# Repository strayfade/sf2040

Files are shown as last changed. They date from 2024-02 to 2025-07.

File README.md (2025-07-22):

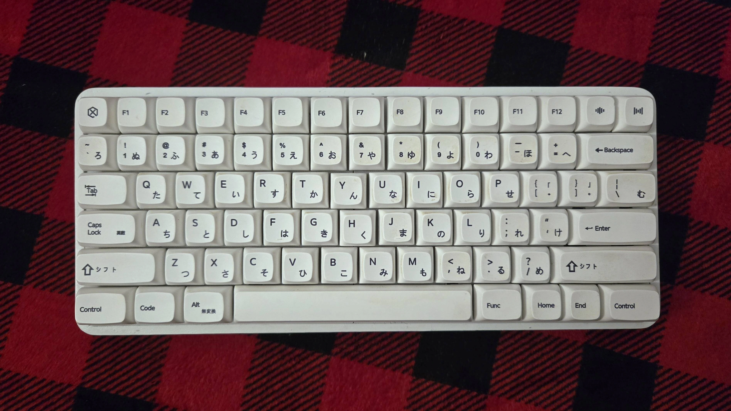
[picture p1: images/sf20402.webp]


<h1 align="center">sf2040</h1>

<p align="center">
    <a href="https://certification.oshwa.org/us002610.html">
        
    </a>
    <a href="https://qmk.fm/">
        
    </a>
</p>

### About

The sf2040 is a mechanical 76-key keyboard based on the [RP2040](https://datasheets.raspberrypi.com/rp2040/rp2040-datasheet.pdf) microcontroller from Raspberry Pi.

> This project has been certified by the OSHWA as open source hardware.
>
> ```html
> [OSHW] US002610 | Certified open source hardware | oshwa.org/cert
> ```

### Features

- USB Type-C Port
- Fully open-source/open-hardware design and firmware files
- **No LED backlight**
- **No Bluetooth/wireless connectivity**

### Assembly/Mechanical Information

**Required** parts:

- PCB ([Download Gerber](/pcb/Gerber/Gerber.zip))
- 3D-printed case ([Download .STEP](/case/Case.step))
- Keyswitch plate ([Download .STEP](/plate/Plate.step))
- _Your choice of 76 full-size MX-style keyswitches_
- MX-style Hot Swap Switch Mounts ([Amazon](https://www.amazon.com/gp/product/B0B4W9YMGM))
- Screw-in PCB Mount Stabilizers ([Amazon](https://www.amazon.com/gp/product/B0CN38CXQ3))

**Optional, but recommended** parts:

- 0.5mm Foam Switch Dampeners ([Amazon](https://www.amazon.com/gp/product/B0B942VCMV))
- Krytox 205 Grade 0 Lubricant
- Switch disassembly tools
- Case filler (I used polyester fiber)

### Firmware

This keyboard runs standard [QMK firmware](https://docs.qmk.fm/#/), configuration for which is included in this repository.

> The firmware can be downloaded pre-configured for this keyboard [here](/firmware/builds/sf2040.uf2).

The contents of the [firmware](/firmware) folder should be copied into QMK's working keyboard directory (usually `qmk_firmware/keyboards`) before building.

Build with support for VIA enabled:

```sh
qmk compile -kb sf2040 -km via
```

The RP2040's bootloader can be accessed by holding the **ESC** key while plugging in the keyboard. Then, simply drag-and-drop the output `.uf2` firmware into the bootloader folder.

This keyboard has been merged into the [QMK repository](https://github.com/qmk/qmk_firmware/tree/master/keyboards) and [VIA's keyboard repository](https://github.com/the-via/keyboards), meaning that it is fully compatible with the VIA online keyboard configuration software ([usevia.app](https://usevia.app))

> For more information about setting up and working with [QMK](https://docs.qmk.fm/#/) keyboard firmware, read the QMK documentation (https://docs.qmk.fm).

### License

The **sf2040** keyboard design and firmware is released under the **GPLv3** license. Contributions and pull requests to this repository are always welcome!

# Gallery

<div align="center">
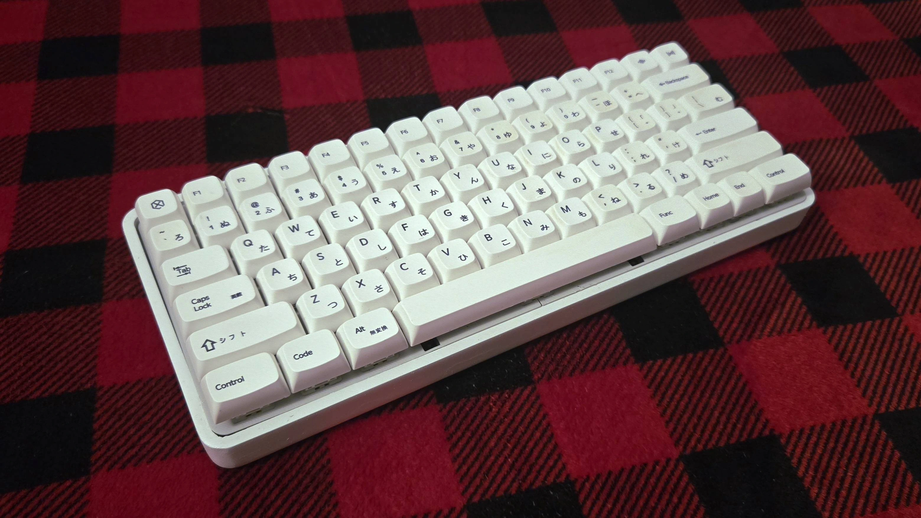
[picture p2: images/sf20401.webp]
    
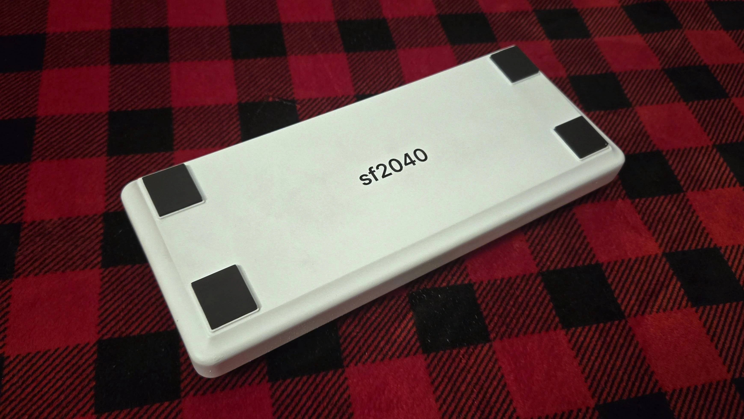
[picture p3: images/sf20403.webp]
    
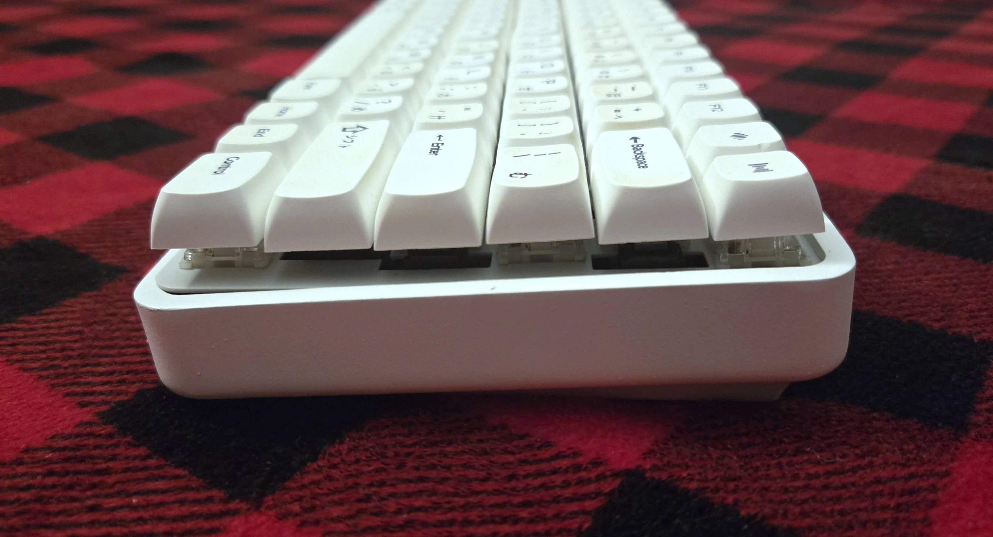
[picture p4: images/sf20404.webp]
    
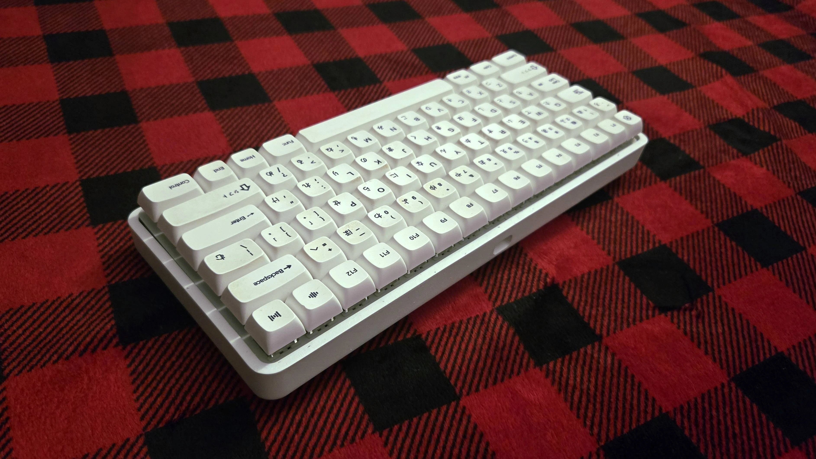
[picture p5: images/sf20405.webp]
    
</div>

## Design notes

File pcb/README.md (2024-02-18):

### PCB Ordering Information
I personally ordered the PCBs pre-assembled from [JLCPCB](https://jlcpcb.com/) using their PCB assembly (PCBA) service. If you also decide to have the boards assembled, I have included the [BOM (.csv)](/pcb/BOM.csv) and the [pick-and-place (.csv)](/pcb/PickAndPlace.csv) files for JLCPCB to use during PCBA.

The board itself does not necessarily **require** any special specifications, but I chose to include the ENIG 1U" gold contact plating for *extra* good measure, just to ensure that neighboring contacts wouldn't be shorted around the RP2040 microcontroller.

All components on the board can be purchased and pre-assembled via the PCBA service except for the switch hot-swap sockets/mounts. These are easy enough to solder freehand and would have greatly added to the cost if included in the PCBA. I highly recommend buying them elsewhere and soldering them yourself. Purchase links for these sockets are included in the top-level [README](/README.md).md

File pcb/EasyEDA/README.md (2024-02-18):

### EasyEDA File Download
This folder includes the raw [EasyEDA](https://easyeda.com/editor) project design files for both the schematic and the PCB for this keyboard.
### Opening in EasyEDA Standard Edition
To open this project, go to [EasyEDA](https://easyeda.com/editor) and open each `.json` file in the editor using **File -> Open -> EasyEDA**
### Gerber File
If you are unfamiliar with EasyEDA or prefer to use another editor/viewer, the raw Gerber design file for this PCB is also included in the **/pcb/Gerber** directory of this repository

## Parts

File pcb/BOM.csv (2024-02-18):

ID | Name | Designator | Footprint | Quantity | Manufacturer Part | Manufacturer | Supplier | Supplier Part | Price
1 | 15pF | C6,C7 | C0402 | 2 | 0402CG150J500NT | FH(风华) | LCSC | C1548 | 0.001
2 | TS-1187A-B-A-B | BT1,BT2 | SW-SMD_4P-L5.1-W5.1-P3.70-LS6.5-TL-2 | 2 | TS-1187A-B-A-B | XKB Connectivity(中国星坤) | LCSC | C318884 | 0.016
3 | 1uF | C1 | C0603 | 1 | CL10A105KB8NNNC | SAMSUNG(三星) | LCSC | C15849 | 0.005
4 | 10uF | C2,C3 | C1206 | 2 | CL31A106KBHNNNE | SAMSUNG(三星) | LCSC | C13585 | 0.034
5 | 2.2uF | C4,C8,C17,C18 | C0603 | 4 | CL10A225KO8NNNC | SAMSUNG(三星) | LCSC | C23630 | 0.006
6 | 100nF | C5,C9,C10,C11,C12,C13,C14,C15,C16 | C0603 | 9 | CC0603KRX7R9BB104 | YAGEO(国巨) | LCSC | C14663 | 0.002
7 | SS210 | D1,D2,D3,D4,D5,D6,D7,D8,D9,D10,D11,D12,D13,D14,D15,D16,D18,D19,D20,D21,D22,D23,D24,D25,D26,D27,D28,D29,D30,D31,D33,D34,D35,D36,D37,D38,D39,D40,D41,D42,D43,D44,D45,D48,D49,D50,D51,D52,D53,D54,D55,D56,D57,D58,D59,D60,D64,D65,D66,D67,D68,D69,D70,D71,D72,D73,D74,D75,D83,D84,D85,D86,D87,D88,D89,D90 | SMA_L4.3-W2.6-LS5.2-RD | 76 | SS210 | MDD | LCSC | C14996 | 0.026
8 | MF-FSMF050X-2 | F1 | F0603 | 1 | MF-FSMF050X-2 | BOURNS | LCSC | C210357 | 0.036
9 | WS2812-2020 | LED1 | LED-SMD_L2.2-W2.0 | 1 | WS2812-2020 | null | LCSC | C9900007650
10 | KT-0603R | LED2 | LED0603-RD | 1 | KT-0603R | KENTO | LCSC | C2286 | 0.006
11 | RP2040 | M1 | LQFN-56_L7.0-W7.0-P0.4-EP | 1 | RP2040 | Raspberry Pi(树莓派) | LCSC | C2040 | 1.076
12 | 5.1kΩ | R1,R2 | R0603 | 2 | 0603WAF5101T5E | UNI-ROYAL(厚声) | LCSC | C23186 | 0.001
13 | 1kΩ | R3,R6 | R0603 | 2 | 0603WAF1001T5E | UNI-ROYAL(厚声) | LCSC | C21190 | 0.001
14 | 10kΩ | R4,R5 | R0603 | 2 | 0603WAF1002T5E | UNI-ROYAL(厚声) | LCSC | C25804 | 0.001
15 | 27Ω | R7,R8 | R0603 | 2 | 0603WAF270JT5E | UNI-ROYAL(厚声) | LCSC | C25190 | 0.001
16 | 200Ω | R9 | R0603 | 1 | 0603WAF2000T5E | UNI-ROYAL(厚声) | LCSC | C8218 | 0.001
17 | CPG151101S11-16 | SW3,SW4,SW5,SW6,SW7,SW8,SW9,SW10,SW11,SW12,SW13,SW14,SW15,SW16,SW18,SW19,SW20,SW21,SW22,SW23,SW24,SW25,SW26,SW27,SW28,SW29,SW30,SW31,SW33,SW34,SW35,SW36,SW37,SW38,SW39,SW40,SW41,SW42,SW43,SW44,SW45,SW48,SW49,SW50,SW51,SW52,SW53,SW54,SW55,SW56,SW57,SW58,SW59,SW60,SW64,SW65,SW66,SW67,SW68,SW69,SW70,SW71,SW72,SW73,SW74,SW75,SW83,SW84,SW85,SW86,SW87,SW88,SW89,SW90,SW1,SW2 | SMD_KEYBOARD-SW | 76 | CPG151101S11-16 | Kailh(凯华) | LCSC | C5156480 | 0.133
18 | AP2112K-3.3TRG1 | U2 | SOT-25-5_L2.9-W1.6-P0.95-LS2.8-BL | 1 | AP2112K-3.3TRG1 | DIODES(美台) | LCSC | C51118 | 0.091
19 | W25Q128JVSIQTR | U3 | SOIC-8_L5.3-W5.3-P1.27-LS8.0-BL | 1 | W25Q128JVSIQ | WINBOND(华邦) | LCSC | C97521 | 0.622
20 | U263-163N-4OS1735 | USBC | USB-C-SMD_U263-163N-4GS1735 | 1 | U263-163N-4OS1735 | XKB Connectivity(中国星坤) | LCSC | C2931472 | 0.264
21 | 12MHz | X1 | OSC-SMD_4P-L3.2-W2.5-BL | 1 | X322512MSB4SI | YXC(扬兴晶振) | LCSC | C9002 | 0.062

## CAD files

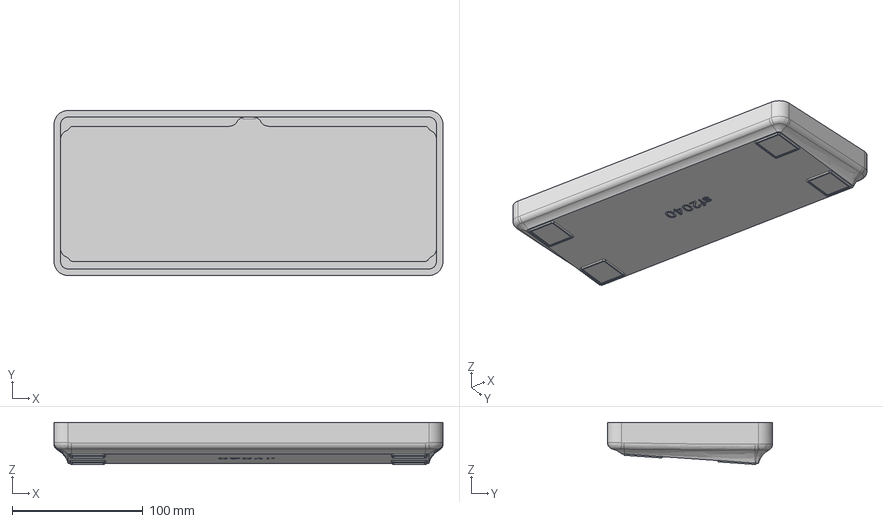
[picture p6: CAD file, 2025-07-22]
case/Case v4.step
297.8 x 126.3 x 32.2 mm

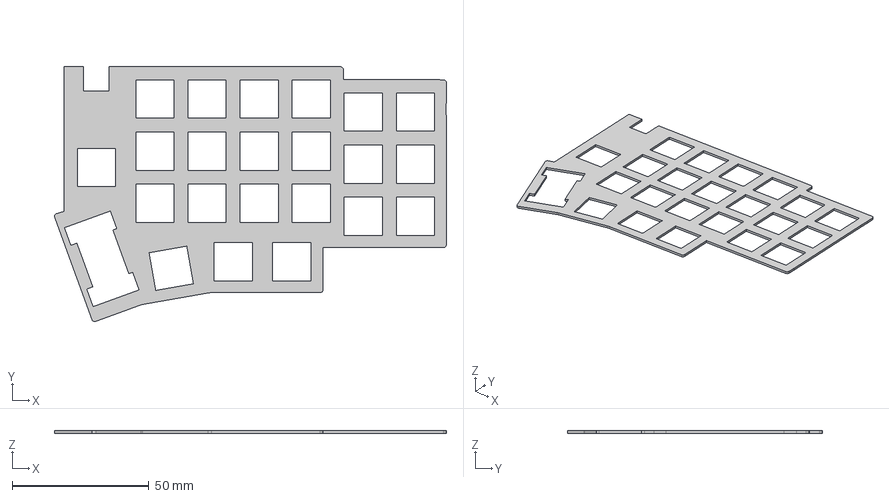
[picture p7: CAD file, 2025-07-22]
plate/plate_v2.step
143.4 x 93.3 x 1.00 mm

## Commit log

2024-02-24 Update plate files
    [Plate.f3d, Plate.step]
2024-03-04 Add V7 case
    [Case.f3d, Case.step]
2025-07-22 New design!
    [Case v4.step, Case.f3d, Case.step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]
